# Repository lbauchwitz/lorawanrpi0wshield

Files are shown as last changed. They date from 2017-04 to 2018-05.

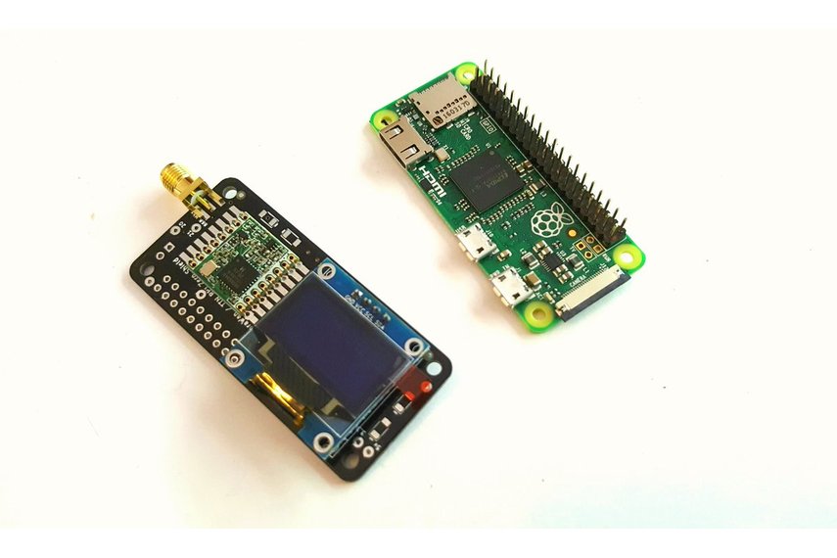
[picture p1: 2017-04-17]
2017-04-13T19-22-51.877Z-C9T4bRGWAAUIY8V.jpg.855x570_q85_pad_rcrop.jpg

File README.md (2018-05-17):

# lorawanrpi0wshield
Work on the design of a 1ch lorawan rpi zero w shield

This is the documentation repo for our LORAWAN TTN Raspberry Pi Zero (W) Shield
The shield has a RFM95 chip, 4 LEDS, 1 SMA Connector and is compatible with RPI0 , RPI2, RPI3

See the txt for more documentation.

PC board can be purchased from here 
https://www.tindie.com/products/electronictrik/raspberry-pi0w-lora-shield-with-i2c-and-oled/

On version 1.2 , there is a mistake on the PCB. The antenna is grounded by accident.
You have to cut a segment. See cut.jpg file . Version 1.3 and Upper are ok with no need to cut

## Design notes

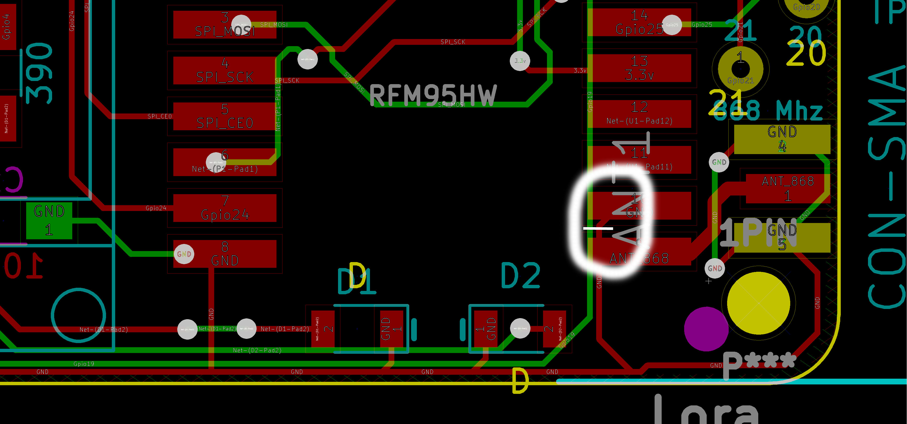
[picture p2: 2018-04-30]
cut1.jpg

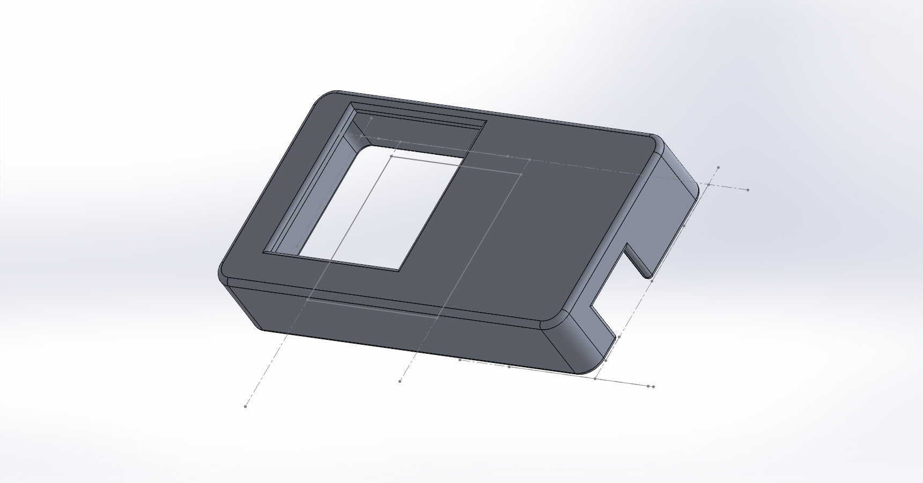
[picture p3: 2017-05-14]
topcover.JPG

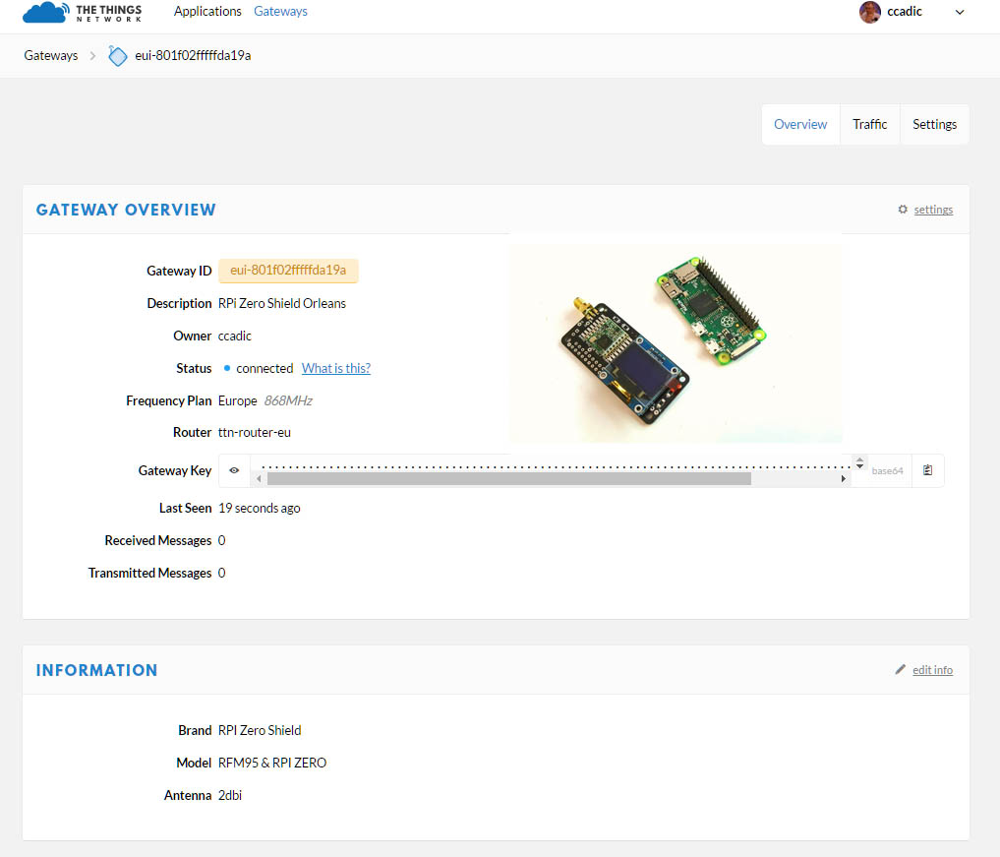
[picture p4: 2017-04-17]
shield6.jpg

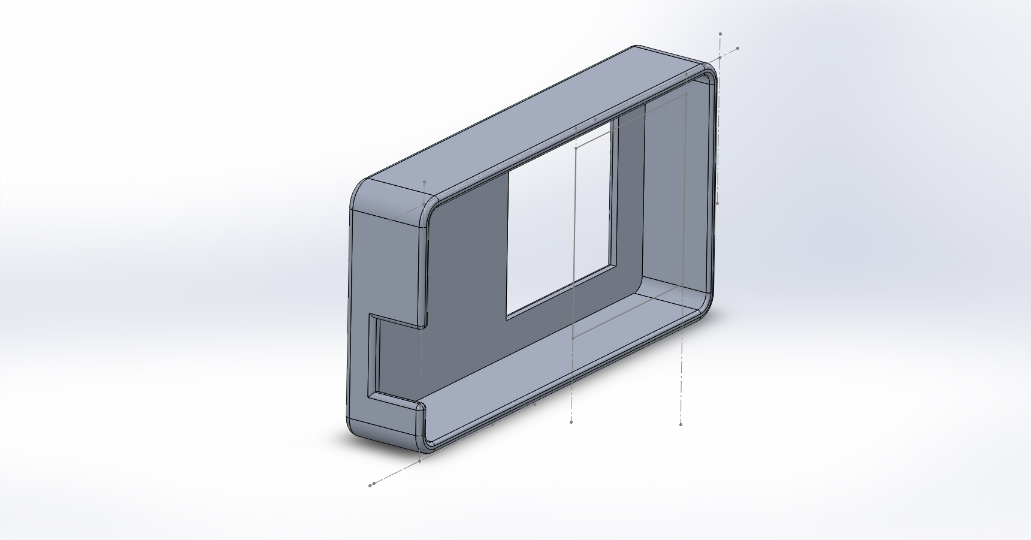
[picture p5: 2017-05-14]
topcover2.JPG

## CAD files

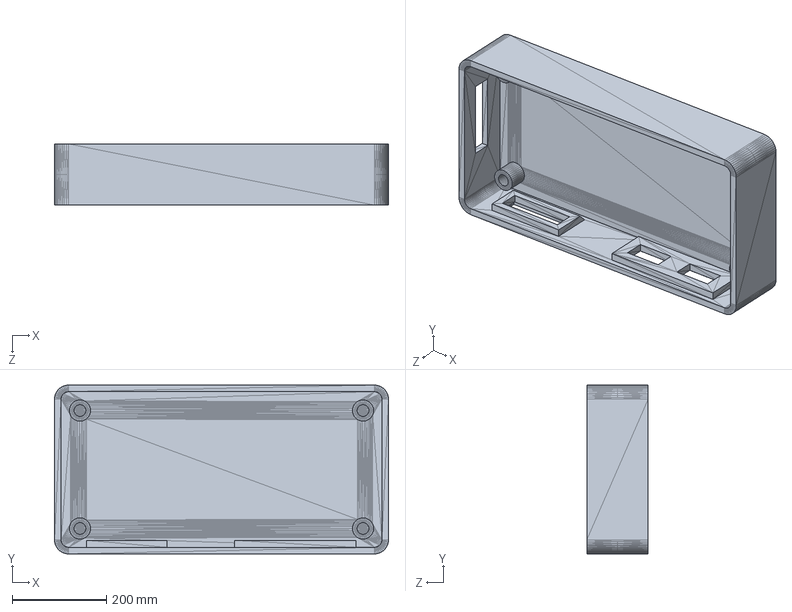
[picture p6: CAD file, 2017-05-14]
lowcase3.SLDPRT
708.0 x 358.0 x 130.0 mm

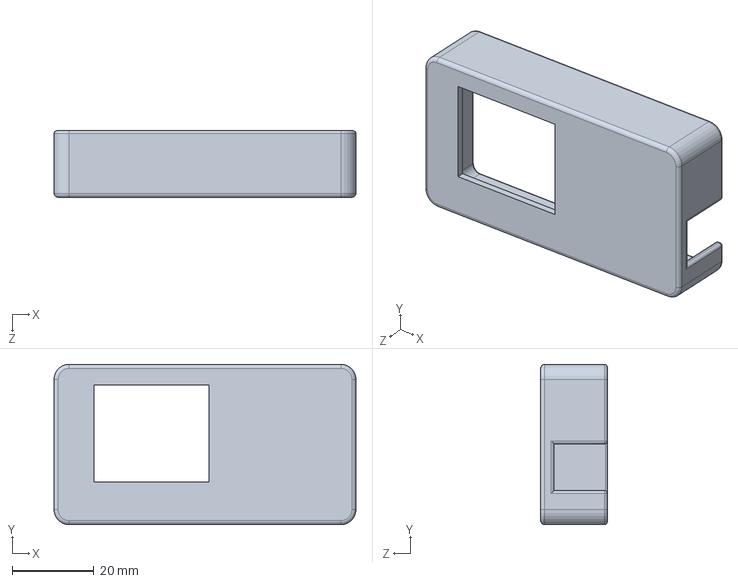
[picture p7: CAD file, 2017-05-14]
topcover.SLDPRT
73.8 x 39.2 x 16.3 mm

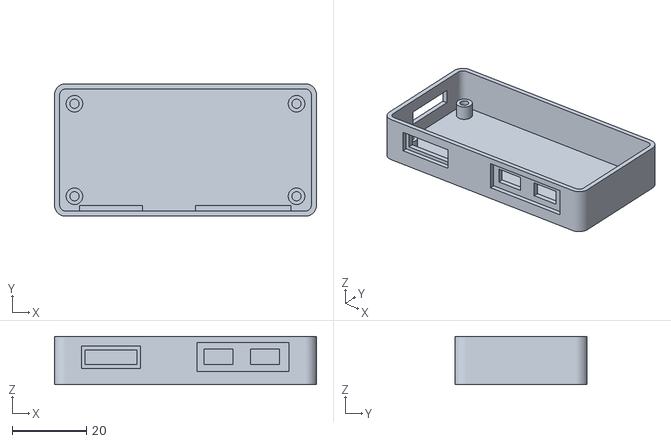
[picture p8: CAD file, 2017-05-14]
lowercase.stl
70.8 x 35.8 x 13.0

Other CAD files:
topcover.STL

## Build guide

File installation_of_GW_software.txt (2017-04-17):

Installation of the PKT Forwarder
Based on the documentation of https://github.com/hallard/single_chan_pkt_fwd

** STEP 1 **
Install bcm2835 library
wget http://www.open.com.au/mikem/bcm2835/bcm2835-1.50.tar.gz
tar xvfz bcm2835-1.50.tar.gz; 
cd bcm2835-1.50;

./configure; 
make; 
sudo make install

Scan the SPI port to find the RFM95
pi@raspberrypi:~/arduino-lmic/examples/raspi/spi_scan $ sudo ./spi_scan
Checking register(0x42) with CS=GPIO06 => Nothing!
Checking register(0x10) with CS=GPIO06 => Nothing!
Checking register(0x42) with CS=GPIO07 => Nothing!
Checking register(0x10) with CS=GPIO07 => Nothing!
Checking register(0x42) with CS=GPIO08 => SX1276 RF95/96 (V=0x12)
Checking register(0x10) with CS=GPIO08 => Nothing!
Checking register(0x42) with CS=GPIO26 => Nothing!
Checking register(0x10) with CS=GPIO26 => Nothing!

** STEP 2 **
Install on the lora pkt forwarder
https://github.com/hallard/single_chan_pkt_fwd

Please note we are on a RPI ZERO with no ETH0 card

EDIT: sudo joe single_chan_pkt_fwd.cpp
Line 691: 
Change 
 strncpy(ifr.ifr_name, "eth0", IFNAMSIZ-1);  // can we rely on eth0?

to
 strncpy(ifr.ifr_name, "wlan0", IFNAMSIZ-1);  // can we rely on eth0?

recompile

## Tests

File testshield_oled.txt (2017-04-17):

install I2C OLE RPI DRIVERS

sudo apt-get install build-essential git-core libi2c-dev i2c-tools lm-sensors

Reboot and verify the i2c and SPI stuff is ok in /dev

pi@raspberrypi:/dev $ ls /dev/i2c*
/dev/i2c-1
pi@raspberrypi:/dev $ ls /dev/spi*
/dev/spidev0.0  /dev/spidev0.1

Installation of the generic Driver
git clone https://github.com/hallard/ArduiPi_OLED

The build install process is in the Makefile, so issue a:
cd ArduiPi_OLED
sudo make

Go to the examples folder and issue a :
sudo make

Send command line

sudo ./oled_demo --verbose --oled 3
oled_demo v1.1
-- OLED params --
Oled is    : Adafruit I2C 128x64

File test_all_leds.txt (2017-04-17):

#!/bin/bash

echo "(c)2017 www.electronictricks.com"
echo "Led test of RPI Zero Lora Shield"

# We set the pin 11 (GPIO 17) for LED operation
echo "Setup of PIN11/GPIO17 for OUT mode"
gpio mode 0 out

# We switch the LED on by sending +3.3v
echo "Switching the LED ON"
gpio write 0 1

# Wait 3 sec until we switch off
sleep 1s

# We switch the LED OFF
echo "Switching the LED on PIN11/GPIO17 off\n"
gpio write 0 0

# We set the pin 7 (GPIO 4) for LED operation
echo "Setup of PIN12/GPIO18 for OUT mode"
gpio mode 1 out

# We switch the LED on by sending +3.3v
echo "Switching the LED ON"
gpio write 1 1

# Wait 3 sec until we switch off
sleep 1s

# We switch the LED OFF
echo "Switching the LED on PIN12/GPIO18 off\n"
gpio write 1 0

# We set the pin 7 (GPIO 4) for LED operation
echo "Setup of PIN35/GPI019 for OUT mode"
gpio mode 24 out

# We switch the LED on by sending +3.3v
echo "Switching the LED ON"
gpio write 24 1

# Wait 3 sec until we switch off
sleep 3s

# We switch the LED OFF
echo "Switching the LED on PIN35/GPIO19 off\n"
gpio write 24 0

# We set the pin 7 (GPIO 4) for LED operation
echo "Setup of PIN7/GPIO4 for OUT mode"
gpio mode 7 out

# We switch the LED on by sending +3.3v
echo "Switching the LED ON"
gpio write 7 1

# Wait 3 sec until we switch off
sleep 3s

# We switch the LED OFF
echo "Switching the LED on PIN7/GPIO4 off\n"
gpio write 7 0

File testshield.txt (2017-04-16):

Testing the SHIELD
Install Raspbian Lite
Once installed and  RPI Zero booted, you have to setup RPI with a 
> sudo raspi-config
Select INTERFACES and activate: I2C and SPI interfaces
Once ok, install the command line WiringRPI with : 
> sudo apt-get install wiringpi

Test the WiringRPI to be working: command is  
> gpio -v

You get something like:
gpio version: 2.44
Copyright (c) 2012-2017 Gordon Henderson
This is free software with ABSOLUTELY NO WARRANTY.
For details type: gpio -warranty

Raspberry Pi Details:
  Type: Pi Zero, Revision: 03, Memory: 512MB, Maker: Embest
  * Device tree is enabled.
  *--> Raspberry Pi Zero Rev 1.3
  * This Raspberry Pi supports user-level GPIO access.

You can get more information on your GPIO config with the commande line

> gpio readall

 +-----+-----+---------+------+---+-Pi Zero--+---+------+---------+-----+-----+
 | BCM | wPi |   Name  | Mode | V | Physical | V | Mode | Name    | wPi | BCM |
 +-----+-----+---------+------+---+----++----+---+------+---------+-----+-----+
 |     |     |    3.3v |      |   |  1 || 2  |   |      | 5v      |     |     |
 |   2 |   8 |   SDA.1 | ALT0 | 1 |  3 || 4  |   |      | 5v      |     |     |
 |   3 |   9 |   SCL.1 | ALT0 | 1 |  5 || 6  |   |      | 0v      |     |     |
 |   4 |   7 | GPIO. 7 |   IN | 1 |  7 || 8  | 1 | ALT0 | TxD     | 15  | 14  |
 |     |     |      0v |      |   |  9 || 10 | 1 | ALT0 | RxD     | 16  | 15  |
 |  17 |   0 | GPIO. 0 |   IN | 0 | 11 || 12 | 0 | IN   | GPIO. 1 | 1   | 18  |
 |  27 |   2 | GPIO. 2 |   IN | 0 | 13 || 14 |   |      | 0v      |     |     |
 |  22 |   3 | GPIO. 3 |   IN | 0 | 15 || 16 | 0 | IN   | GPIO. 4 | 4   | 23  |
 |     |     |    3.3v |      |   | 17 || 18 | 1 | IN   | GPIO. 5 | 5   | 24  |
 |  10 |  12 |    MOSI | ALT0 | 0 | 19 || 20 |   |      | 0v      |     |     |
 |   9 |  13 |    MISO | ALT0 | 0 | 21 || 22 | 0 | IN   | GPIO. 6 | 6   | 25  |
 |  11 |  14 |    SCLK | ALT0 | 0 | 23 || 24 | 1 | OUT  | CE0     | 10  | 8   |
 |     |     |      0v |      |   | 25 || 26 | 1 | OUT  | CE1     | 11  | 7   |
 |   0 |  30 |   SDA.0 |   IN | 1 | 27 || 28 | 1 | IN   | SCL.0   | 31  | 1   |
 |   5 |  21 | GPIO.21 |   IN | 1 | 29 || 30 |   |      | 0v      |     |     |
 |   6 |  22 | GPIO.22 |   IN | 1 | 31 || 32 | 0 | IN   | GPIO.26 | 26  | 12  |
 |  13 |  23 | GPIO.23 |   IN | 0 | 33 || 34 |   |      | 0v      |     |     |
 |  19 |  24 | GPIO.24 |   IN | 0 | 35 || 36 | 0 | IN   | GPIO.27 | 27  | 16  |
 |  26 |  25 | GPIO.25 |   IN | 0 | 37 || 38 | 0 | IN   | GPIO.28 | 28  | 20  |
 |     |     |      0v |      |   | 39 || 40 | 0 | IN   | GPIO.29 | 29  | 21  |
 +-----+-----+---------+------+---+----++----+---+------+---------+-----+-----+
 | BCM | wPi |   Name  | Mode | V | Physical | V | Mode | Name    | wPi | BCM |
 +-----+-----+---------+------+---+-Pi Zero--+---+------+---------+-----+-----+

Test LED of the SHIELD from command line

Test: LED GIO04 (PIN7)
> gpio mode 7 out
> gpio write 7 1

The LED should light on
To switch it off

> gpio write 7 0
